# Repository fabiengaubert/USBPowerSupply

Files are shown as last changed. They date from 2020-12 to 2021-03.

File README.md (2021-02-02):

# USBPowerSupply

USB Power supply design for eurorack, works with powerbanks or good USB wallwarts

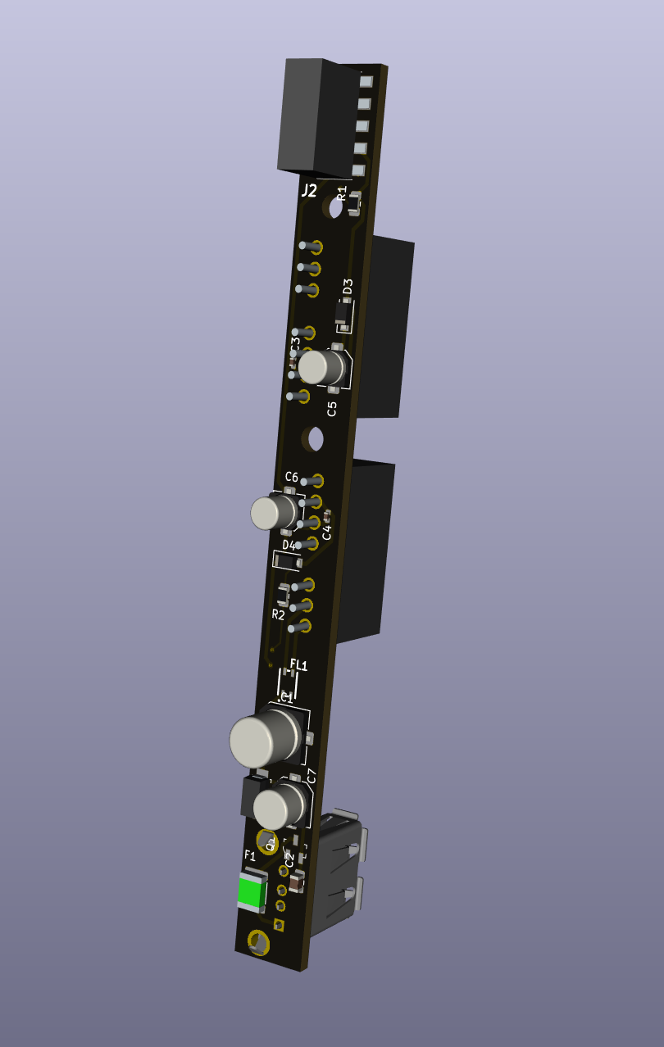
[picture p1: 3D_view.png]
3D view


- 2 HP
- 500mA at +12v, 500mA at - 12v
- efficient isolated DC-DC switching regulators with low heat release
- surge voltage and over-current protection with resettable fuse
- reversed polarity protection
- common mode choke and multiple ferrite beads with PI filters for noise filtering
- 1 LED per rail to indicated overload and short circuits

Warning and reserves:
- the two DC-DC switching regulators are expensive compared to the rest of the components: they represent about 75% of the total cost, I will work on a cheaper version with at least the same performances in the future
- the minimum voltage allowed is 4.5v, which we know can be too much for USB chargers, as they are unregulated sources of voltage. when current rises above 0.5A, most of them drop the voltage below this value. There is a need to test chargers and advise specific ones. With power banks they should be no problems as their output is regulated

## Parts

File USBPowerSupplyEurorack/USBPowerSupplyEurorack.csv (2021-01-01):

Comment | Designator | Footprint | LCSC
220uF | C1 | Capacitor_SMD:C_Elec_6.3x7.7 | C127327
22uF | C2 | Capacitor_SMD:C_0805_2012Metric | C45783
100nF | C3,C4 | Capacitor_SMD:C_0402_1005Metric | C1525
4.7uF | C5,C6 | Capacitor_SMD:C_Elec_4x5.4 | C116398
47uF | C7 | Capacitor_SMD:C_Elec_5x5.4 | C294514
SMAJ5.0CA | D1 | digikey-footprints:DO-214AC-BIPOLAR | C151931
1N4007 | D3,D4 | Diode_SMD:D_SOD-123F | C64898
1812L110 | F1 | Fuse:Fuse_1812_4532Metric | C163516
ACP3225-102-2P-T000 | FL1 | ACP3225-102-2P-T000:ACP3225 | C92126
1734366-1 | J1 | 1734366-1:TE_1734366-1
95278-501A10LF | J2 | 95278-501A10LF:95278501A10LF
RS6-0512S | PS1,PS2 | RS6-0512S:RS60512S
Q_PMOS_GSD | Q1 | digikey-footprints:SOT-23-3 | C15127
1K | R1 | Resistor_SMD:R_0805_2012Metric | C17513
Blue switch | S1 | LP4OA1PBCTR:LP4OA1PBCTR

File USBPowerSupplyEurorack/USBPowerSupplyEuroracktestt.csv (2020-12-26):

Reference | Quantity | Value | Footprint | Datasheet | Centerline_Pitch | Comment | EU_RoHS_Compliance | Number_of_Positions | Product_Type | Description | Height | Manufacturer_Name | Manufacturer_Part_Number | Mouser Part Number | Mouser Price/Stock | Arrow Part Number | Arrow Price/Stock | category | digikey description | digikey part number | lead free | library id | manufacturer | mouser part number | package | rohs | temperature range high | temperature range low | voltage
C1 | 1 | 220uF | Capacitor_SMD:C_Elec_8x10.2 | ~
C2 | 1 | 22uFMLCC | Capacitor_SMD:C_1210_3225Metric | ~
C3 C4 | 2 | 100nF MLCC | Capacitor_SMD:C_1206_3216Metric | ~
C5 C6 | 2 | 1uF | Capacitor_SMD:C_Elec_4x5.4 | ~
C7 | 1 | 47uF | Capacitor_SMD:C_Elec_6.3x5.8 | ~
D1 | 1 | SMAJ5.0CA | DIONM5026X229N | http://www.littelfuse.com/~/media/electronics/datasheets/tvs_diodes/littelfuse_tvs_diode_smaj_datasheet.pdf.pdf |  |  |  |  |  | Littelfuse SMAJ5.0CA Bi-Directional TVS Diode, 400W peak, 2-Pin DO-214AC | 2.29 | LITTELFUSE | SMAJ5.0CA | 576-SMAJ5.0CA | https://www.mouser.co.uk/ProductDetail/Littelfuse/SMAJ50CA?qs=JJML70Qc14u8hb22RFwTwA%3D%3D | SMAJ5.0CA | https://www.arrow.com/en/products/smaj5.0ca/littelfuse
D3 D4 | 2 | 1N4004 | Diode_SMD:D_SOD-123F | http://www.vishay.com/docs/88503/1n4001.pdf
F1 | 1 | 1812L110 | 1812L110_16DR:FUSC4632X125N | https://www.arrow.com/en/products/1812l11016dr/littelfuse |  |  |  |  |  | PTC Resettable Fuse 1.1A(hold) 1.95A(trip) 8VDC 100A 0.8W 0.3s 0.06Ohm SMD Solder Pad 1812 T/R | 1.25 | LITTELFUSE | 1812L110/16DR | 576-1812L110/16DR | https://www.mouser.co.uk/ProductDetail/Littelfuse/1812L110-16DR?qs=PWhpLWeW8we3Ga3SZHmLHg%3D%3D | 1812L110/16DR | https://www.arrow.com/en/products/1812l11016dr/littelfuse
J1 | 1 | 1734366-1 | 1734366-1:TE_1734366-1 |  | 2 mm[.078 in] | 1734366-1 | Compliant | 4 | Connector
J2 | 1 | 10129381-910001BLF | 10129381-910001BLF:HDRV10W67P254_2X5_1270X483X858P | https://cdn.amphenol-icc.com/media/wysiwyg/files/drawing/10129381.pdf |  |  |  |  |  | EconoStik , Board to Board connector, Unshrouded Vertical Header, Through Hole, Double Row, 10 Positions, 2.54 mm (0.100in) Pitch | 8.58 | Amphenol | 10129381-910001BLF | 649-1012938191001BLF | https://www.mouser.co.uk/ProductDetail/Amphenol-FCI/10129381-910001BLF?qs=0lQeLiL1qyYhmE%2FYsfo%2FnQ%3D%3D | 10129381-910001BLF | https://www.arrow.com/en/products/10129381-910001blf/amphenol-fci
L1 | 1 | ACM4520V-901-2P-T | eec2:TDK-ACM4520V-901-2P-T-0 | http://nl.rs-online.com/webdocs/14e9/0900766b814e92ac.pdf |  |  |  |  |  |  |  |  |  |  |  |  |  | Fuse | 2 Line Common Mode Choke Surface Mount 900 Ohm @ 100MHz 1.2A DCR 60 mOhm | 445-15677-1-ND | yes | 40a722fe90742dbf | TDK | 810-ACM4520V9012PT00 | L1808 | yes | +125°C | -40°C | 50V
PS1 PS2 | 2 | RS6-0512S | RS6-0512S:RS60512S | https://componentsearchengine.com/Datasheets/1/RS6-0512S.pdf |  |  |  |  |  | Isolated DC/DC Converters 6W 4.5-9Vin 12Vout 500mA SIP8 | 11.6 | RECOM Power | RS6-0512S | 919-RS6-0512S | https://www.mouser.co.uk/ProductDetail/RECOM-Power/RS6-0512S?qs=FLBwGrBR9%252B1rp7zTwCRMhw%3D%3D
Q1 | 1 | Q_PMOS_GSD | digikey-footprints:SOT-23-3 | https://www.mouser.fr/datasheet/2/916/PMV240SP-1919536.pdf
R1 | 1 | 510 | Resistor_SMD:R_0612_1632Metric | ~
S1 | 1 | LP4OA1PBCTR | LP4OA1PBCTR:LP4OA1PBCTR | http://spec_sheets.e-switch.com/specs/B240001.pdf |  |  |  |  |  | Pushbutton Switches DPDT On-Mom LED, Red | 19.95 | E-Switch | LP4OA1PBCTR | 612-LP4OA1PBCTR | https://www.mouser.com/Search/Refine.aspx?Keyword=612-LP4OA1PBCTR

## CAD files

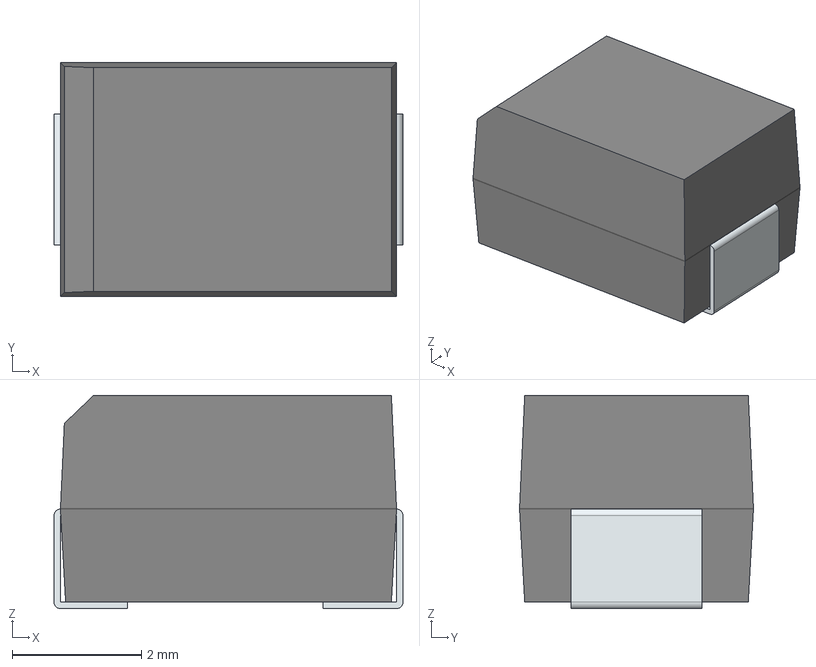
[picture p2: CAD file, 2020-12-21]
USBPowerSupplyEurorack/CustomSymbols/LIB_LSM115JE3_TR13/LSM115JE3_TR13/3D/LSM115JE3_TR13.stp
5.40 x 3.62 x 3.30 mm
FilletPin1
FilletPin2

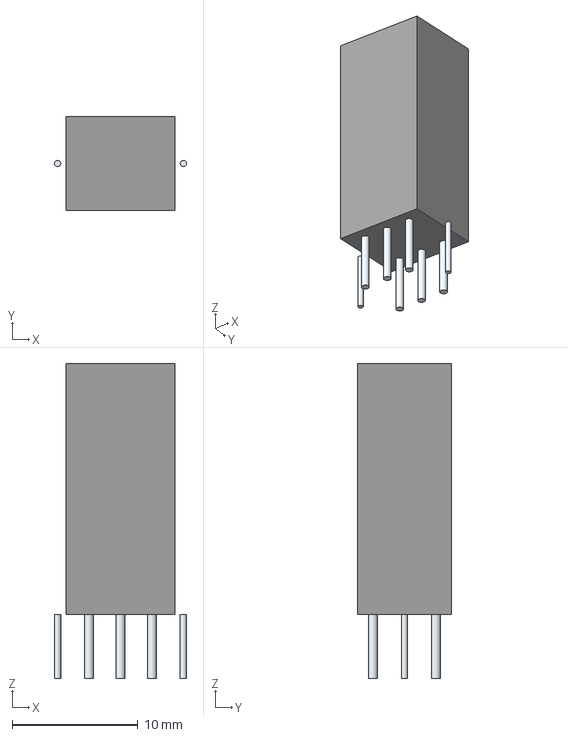
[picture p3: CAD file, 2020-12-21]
USBPowerSupplyEurorack/CustomSymbols/LP4-switch/3D/LP4OA1PBCTR.stp
10.5 x 7.50 x 25.1 mm
Leads x 8

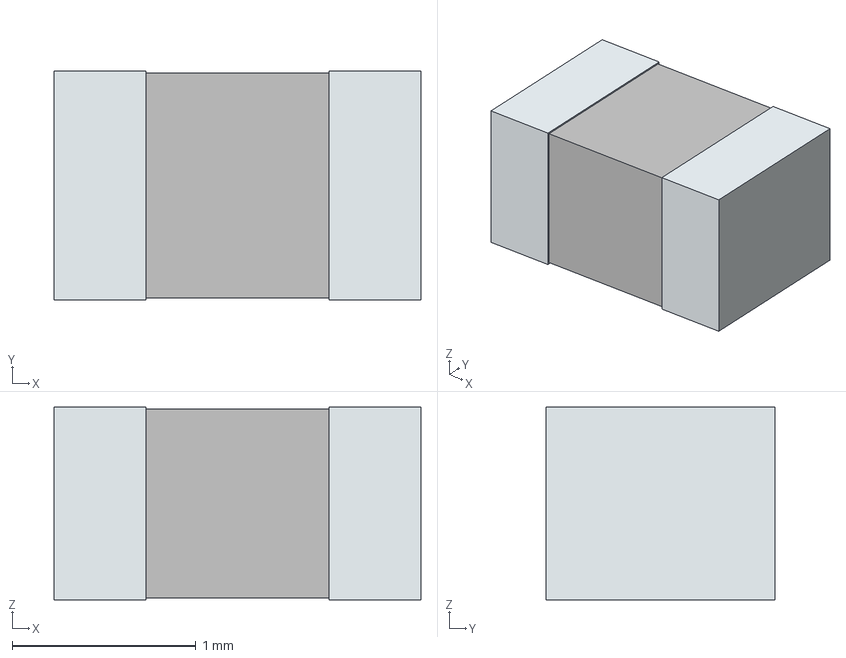
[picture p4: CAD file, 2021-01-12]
USBPowerSupplyEurorack/CustomSymbols/MPZ2012S101AT000/3D/MPZ2012S101AT000.stp
2.00 x 1.25 x 1.05 mm
term1
term2

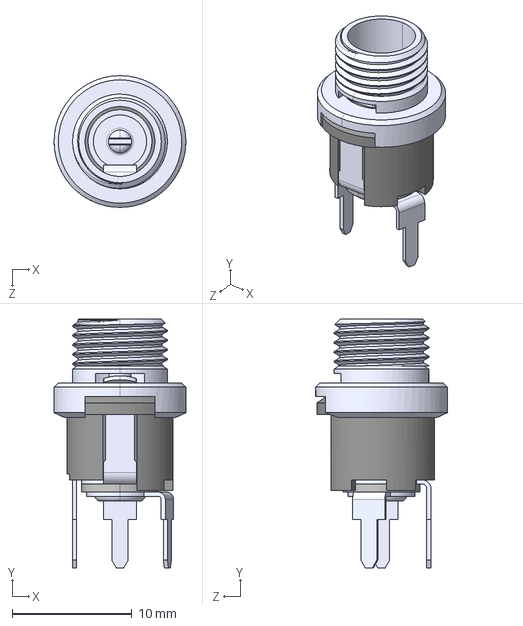
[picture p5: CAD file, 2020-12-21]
USBPowerSupplyEurorack/CustomSymbols/PC722A/PC722A.step
11.0 x 20.8 x 11.0 mm

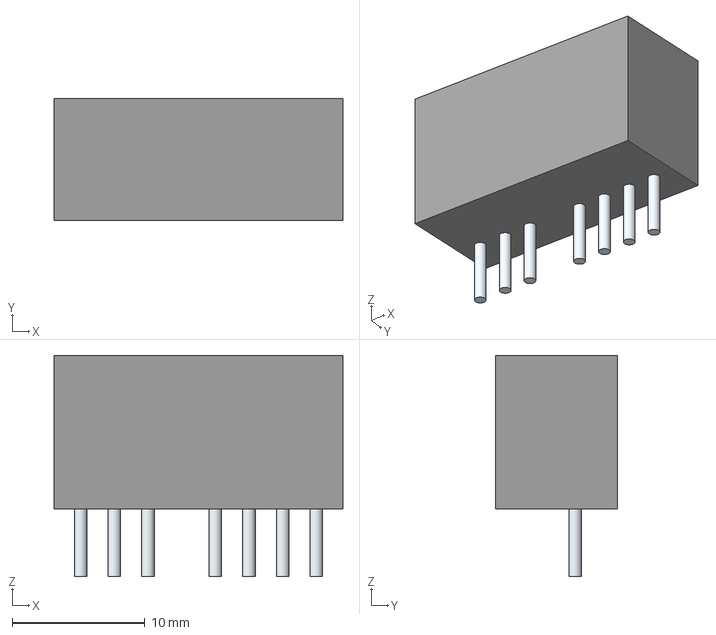
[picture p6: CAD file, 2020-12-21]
USBPowerSupplyEurorack/CustomSymbols/RS6-0512D/3D/RS6-0512D.stp
21.8 x 9.20 x 16.7 mm
Leads

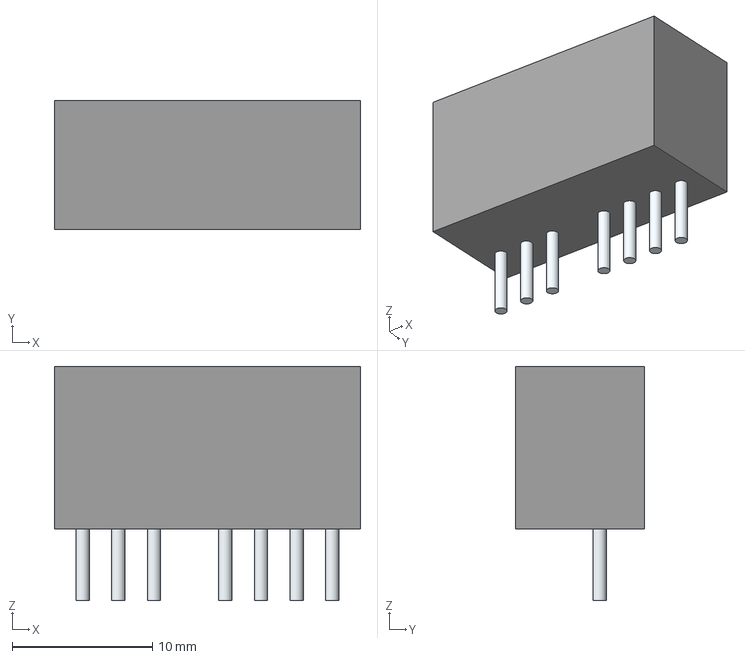
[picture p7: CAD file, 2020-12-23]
USBPowerSupplyEurorack/CustomSymbols/RS6-0512S/3D/RS6-0512S.stp
21.8 x 9.20 x 16.7 mm
Leads x 7

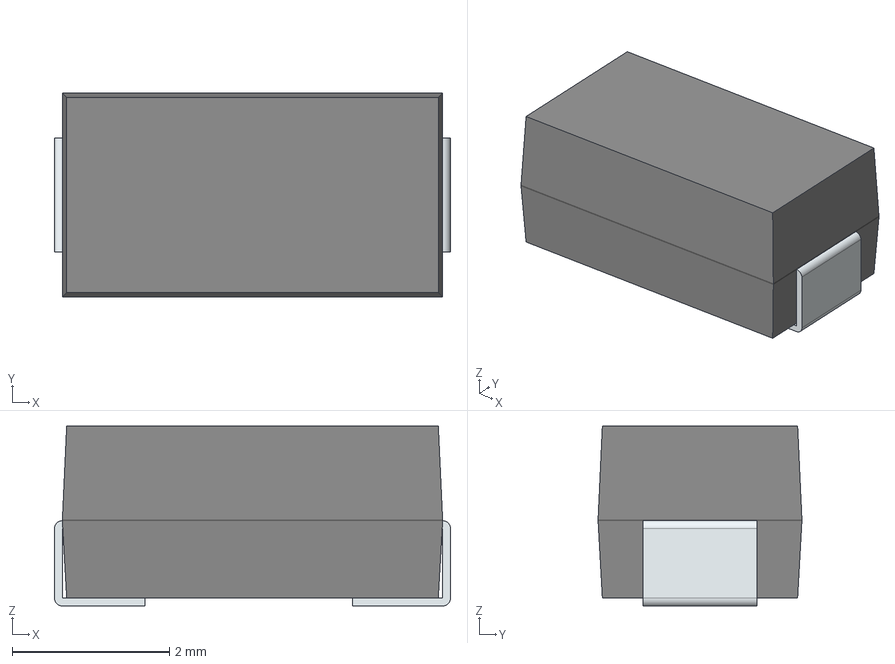
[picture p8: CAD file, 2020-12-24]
USBPowerSupplyEurorack/CustomSymbols/SMAJ5.0CA/3D/SMAJ5.0CA.stp
5.04 x 2.60 x 2.29 mm
FilletPin1
FilletPin2

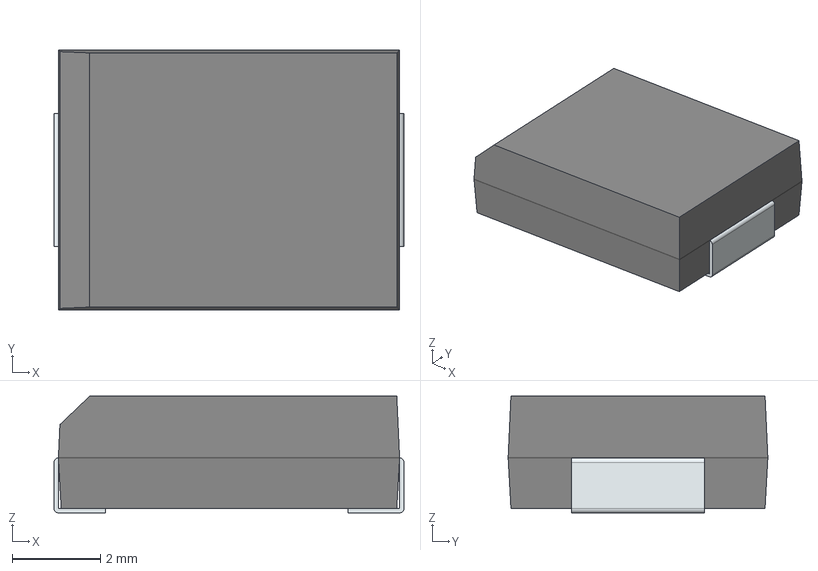
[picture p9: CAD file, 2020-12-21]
USBPowerSupplyEurorack/CustomSymbols/SS36/3D/SS36.stp
7.95 x 5.90 x 2.65 mm
FilletPin1
FilletPin2

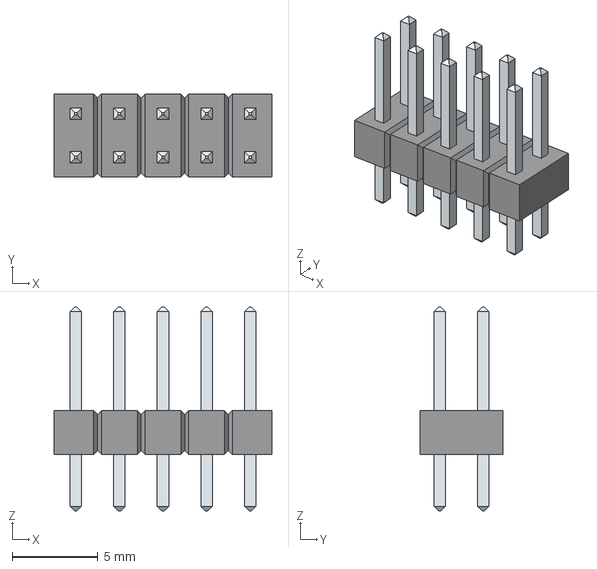
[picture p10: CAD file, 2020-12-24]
USBPowerSupplyEurorack/CustomSymbols/10129381-910001BLF/3D/10129381-910001BLF.stp
12.7 x 4.83 x 11.9 mm
LeadsArray

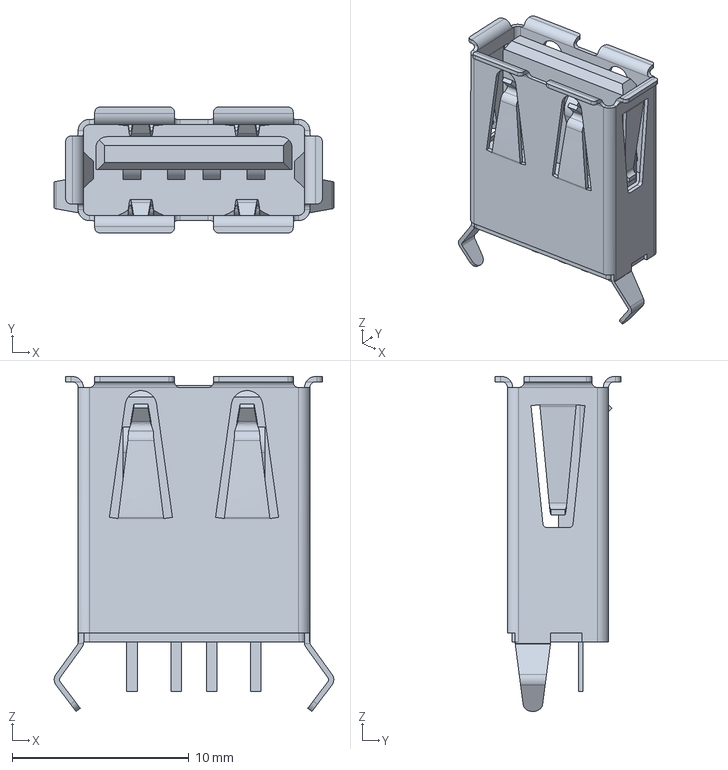
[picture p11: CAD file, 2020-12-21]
USBPowerSupplyEurorack/CustomSymbols/1734366-1/108861197-19-1734366-1/1734366-1.stp
15.8 x 7.12 x 18.9 mm

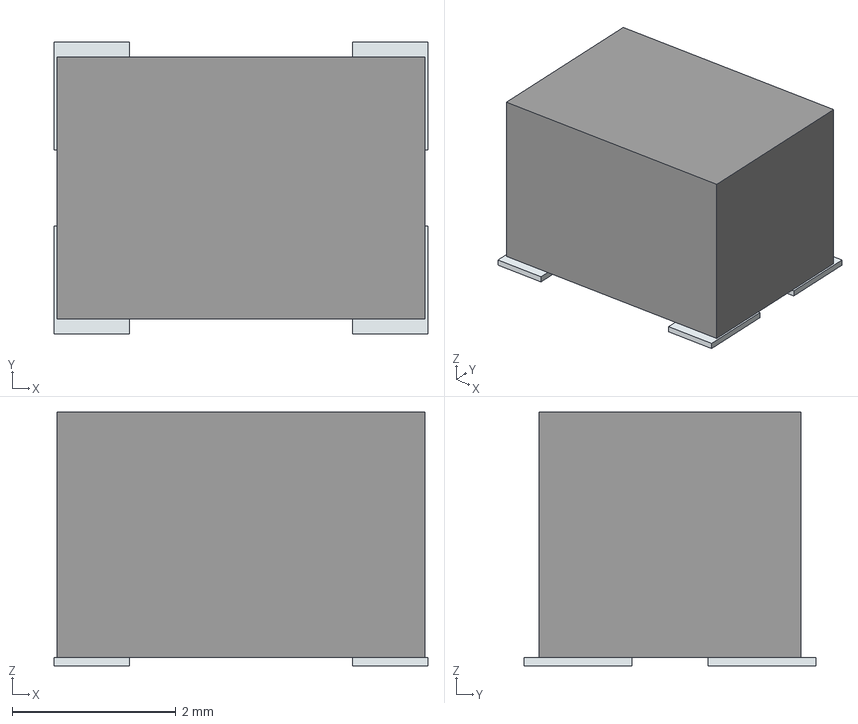
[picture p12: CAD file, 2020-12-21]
USBPowerSupplyEurorack/CustomSymbols/744235601/3D/744235601.stp
4.57 x 3.57 x 3.10 mm
Pins

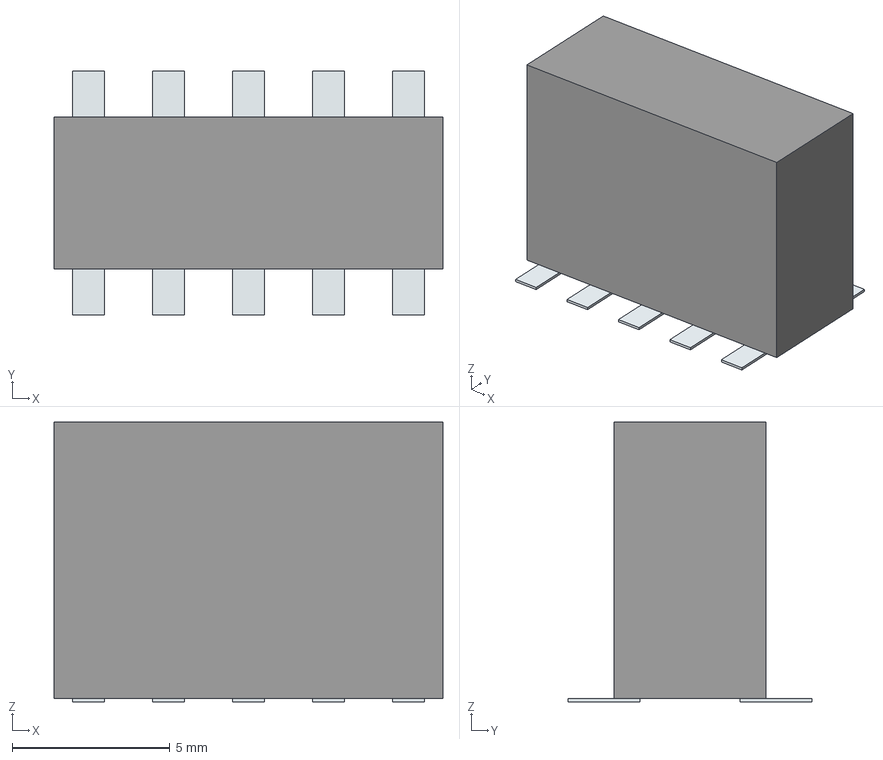
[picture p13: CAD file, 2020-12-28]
USBPowerSupplyEurorack/CustomSymbols/95278-501A10LF/3D/95278-501A10LF.stp
12.3 x 7.75 x 8.87 mm
Pins

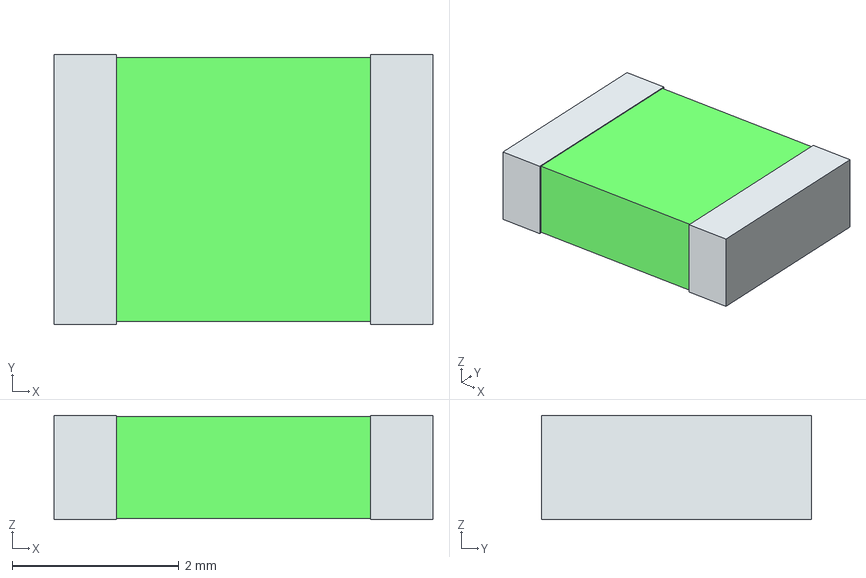
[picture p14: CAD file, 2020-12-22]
USBPowerSupplyEurorack/CustomSymbols/LIB_1812L110_16DR/3D/1812L110_16DR.stp
4.55 x 3.24 x 1.25 mm
term1
term2

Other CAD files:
USBPowerSupplyEurorack/CustomSymbols/10129381-910001BLF/3D/10129381-910001BLF.stl
USBPowerSupplyEurorack/CustomSymbols/744235601/3D/744235601.stl
USBPowerSupplyEurorack/CustomSymbols/95278-501A10LF/3D/95278-501A10LF.stl
USBPowerSupplyEurorack/CustomSymbols/LIB_1812L110_16DR/3D/1812L110_16DR.stl
USBPowerSupplyEurorack/CustomSymbols/LIB_LSM115JE3_TR13/LSM115JE3_TR13/3D/LSM115JE3_TR13.stl
USBPowerSupplyEurorack/CustomSymbols/LIB_PC722A/PC722A/Allegro/pc722a.psm
USBPowerSupplyEurorack/CustomSymbols/LIB_PC722A/PC722A/DEHDL/pc722a/chips/chips.prt
USBPowerSupplyEurorack/CustomSymbols/LP4-switch/3D/LP4OA1PBCTR.stl
USBPowerSupplyEurorack/CustomSymbols/MPZ2012S101AT000/3D/MPZ2012S101AT000.stl
USBPowerSupplyEurorack/CustomSymbols/RS6-0512D/3D/RS6-0512D.stl
USBPowerSupplyEurorack/CustomSymbols/RS6-0512S/3D/RS6-0512S.stl
USBPowerSupplyEurorack/CustomSymbols/SMAJ5.0CA/3D/SMAJ5.0CA.stl
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

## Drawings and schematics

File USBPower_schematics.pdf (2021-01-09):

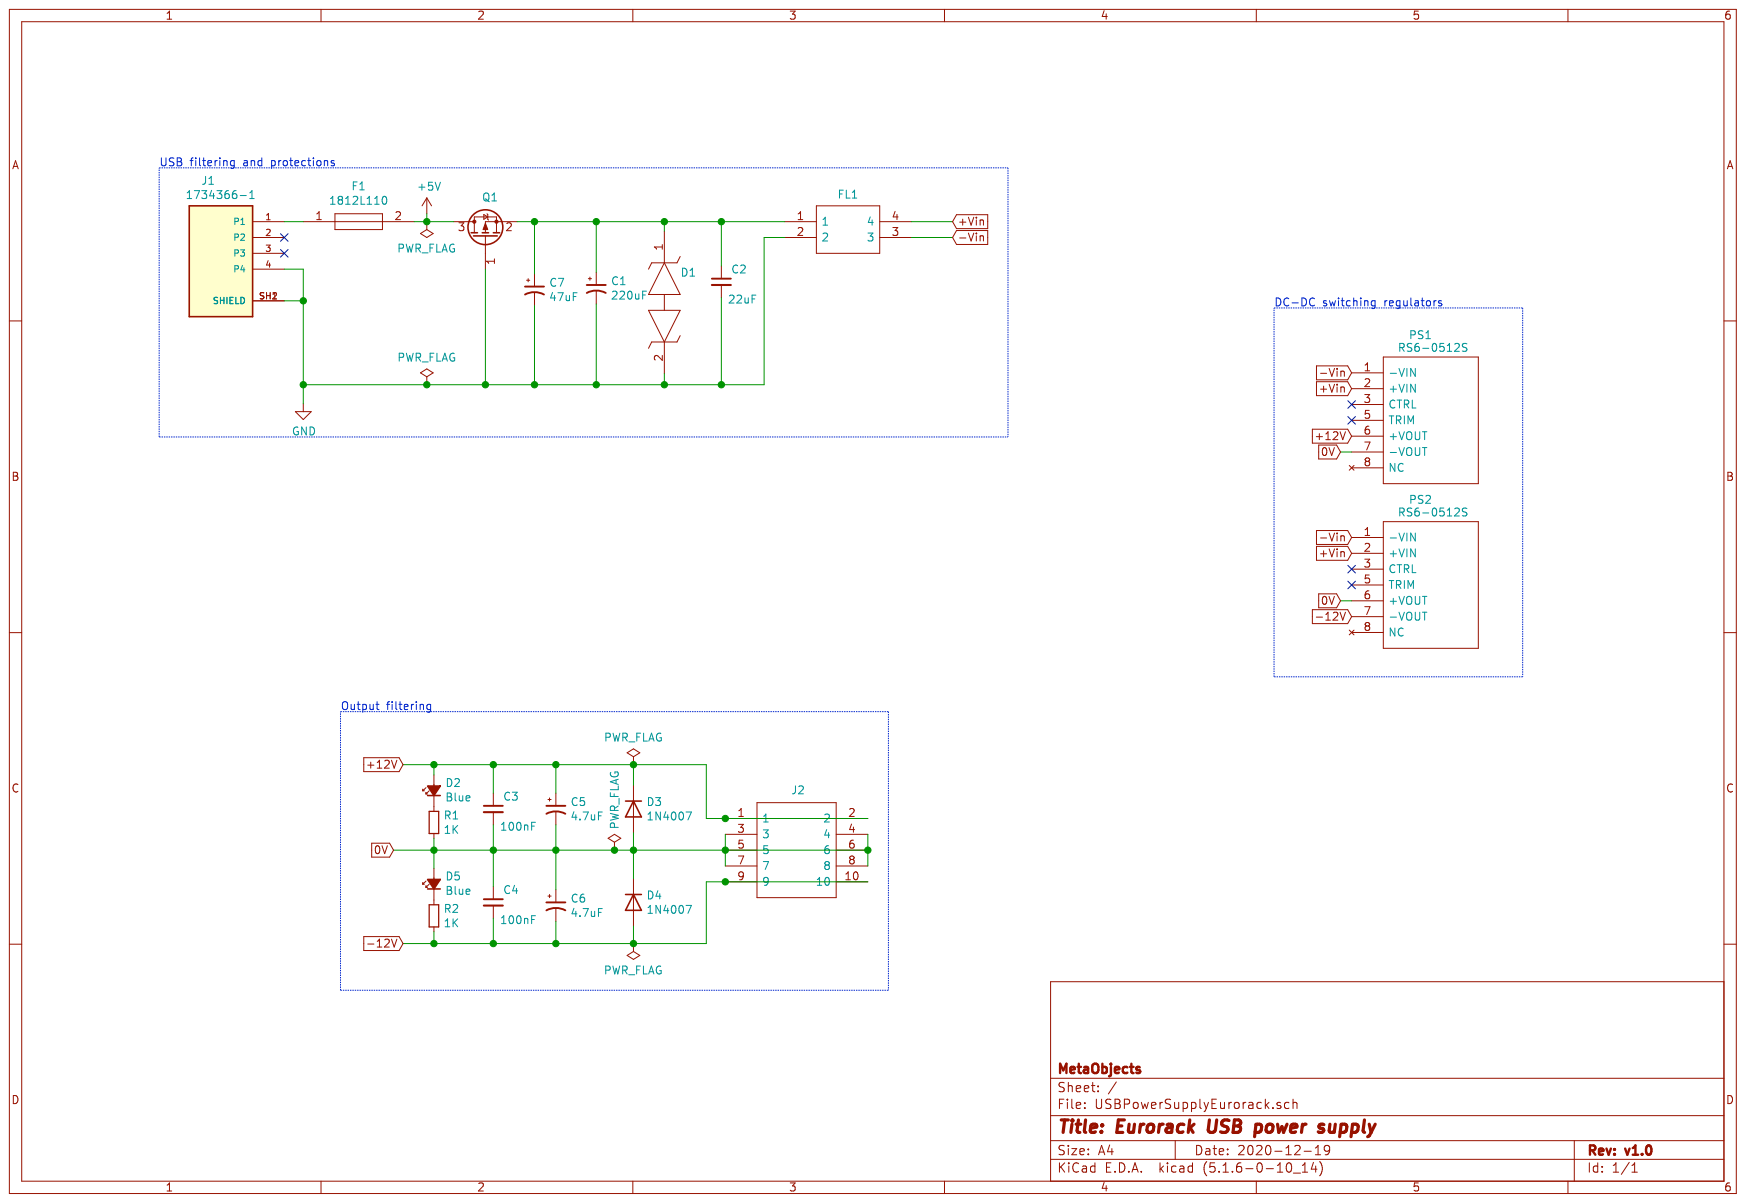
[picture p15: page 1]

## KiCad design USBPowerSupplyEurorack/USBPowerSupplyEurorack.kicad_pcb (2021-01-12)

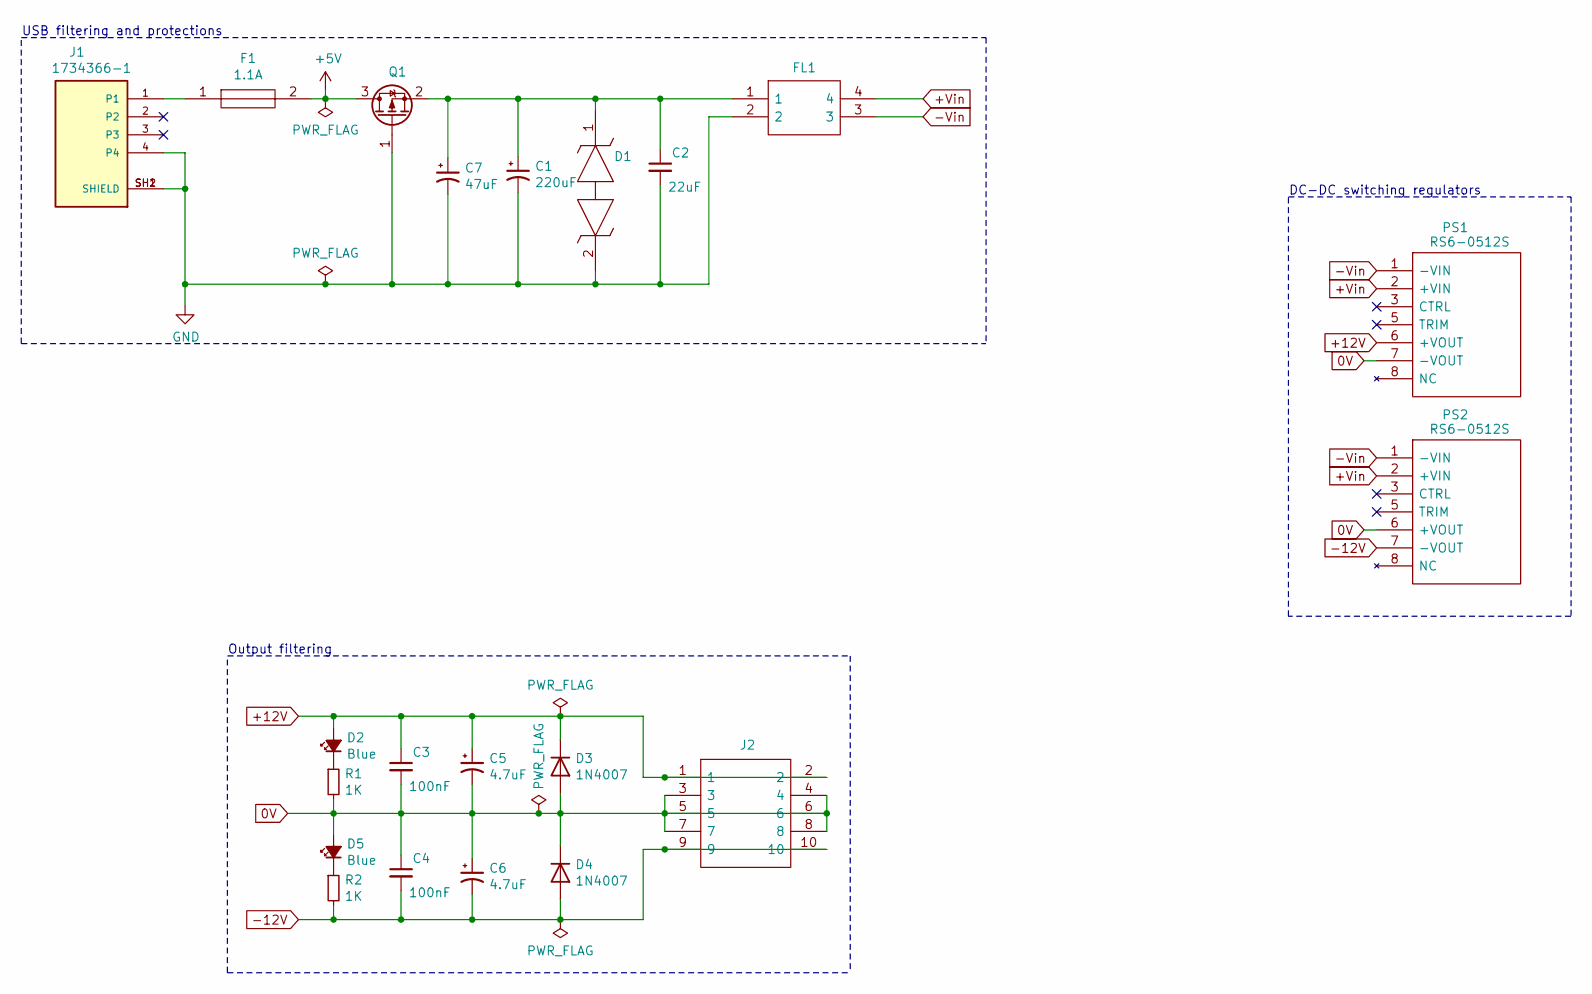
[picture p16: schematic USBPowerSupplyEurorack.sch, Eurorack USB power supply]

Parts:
C1: 220uF; C_Elec_6.3x7.7; LCSC C127327
C2: 22uF; C_0805_2012Metric; LCSC C45783
C3, C4: 100nF; C_0402_1005Metric; LCSC C1525
C5, C6: 4.7uF; C_Elec_4x5.4; LCSC C116398
C7: 47uF; C_Elec_5x5.4; LCSC C294514
D1: SMAJ5.0CA; DO-214AC-BIPOLAR; Manufacturer_Part_Number SMAJ5.0CA; Mouser Part Number 576-SMAJ5.0CA
D2, D5: Blue; LED_0603
D3, D4: 1N4007; D_SOD-123F; LCSC C64898
F1: 1.1A; Fuse_1812_4532Metric; Manufacturer_Part_Number 1812L110/16DR; Mouser Part Number 576-1812L110/16DR
FL1: ACP3225-102-2P-T000; ACP3225; Manufacturer_Part_Number ACP3225-102-2P-T000; Mouser Part Number 810-ACP32251022PT000
J1: 1734366-1; TE_1734366-1
J2: 95278-501A10LF; 95278501A10LF; Manufacturer_Part_Number 95278-501A10LF; Mouser Part Number 649-95278-501A10LF
PS1, PS2: RS6-0512S; RS60512S; Manufacturer_Part_Number RS6-0512S; Mouser Part Number 919-RS6-0512S
Q1: Q_PMOS_GSD; SOT-23-3; LCSC C15127
R1, R2: 1K; R_0805_2012Metric; LCSC C17513

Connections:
0V: C3.2, C4.1, C5.2, C6.1, D3.2 (A), D4.1 (K), D5.2 (A), J2.3, J2.4, J2.5, J2.6, J2.7, J2.8, PS1.7 (-VOUT), PS2.6 (+VOUT), R1.2
+5V: F1.2, Q1.3 (D)
+12V: C3.1, C5.1, D2.2 (A), D3.1 (K), J2.1, J2.2, PS1.6 (+VOUT)
+Vin: FL1.4, PS1.2 (+VIN), PS2.2 (+VIN)
-12V: C4.2, C6.2, D4.2 (A), J2.9, J2.10, PS2.7 (-VOUT), R2.2
-Vin: FL1.3, PS1.1 (-VIN), PS2.1 (-VIN)
GND: C1.2, C2.2, C7.2, D1.2, FL1.2, J1.4, J1.SH1 (SHIELD), J1.SH2 (SHIELD), Q1.1 (G)
unnamed: C1.1, C2.1, C7.1, D1.1, FL1.1, Q1.2 (S)
unnamed: D2.1 (K), R1.1
unnamed: D5.1 (K), R2.1
unnamed: F1.1, J1.1

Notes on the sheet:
USB filtering and protections
DC-DC switching regulators
Output filtering

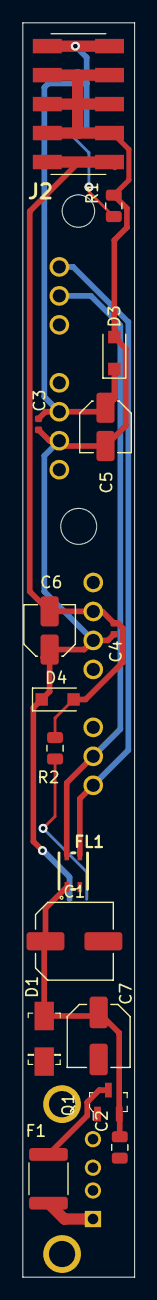
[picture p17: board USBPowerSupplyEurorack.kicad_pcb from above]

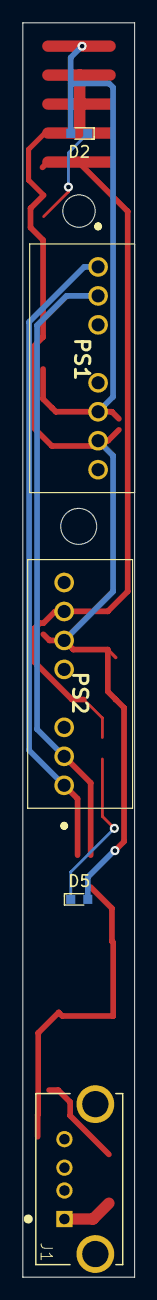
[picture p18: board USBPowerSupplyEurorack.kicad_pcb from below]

Board: 2 copper layers, 9.8 x 110.0 mm, 21 parts (5 on the bottom side), 11 nets.

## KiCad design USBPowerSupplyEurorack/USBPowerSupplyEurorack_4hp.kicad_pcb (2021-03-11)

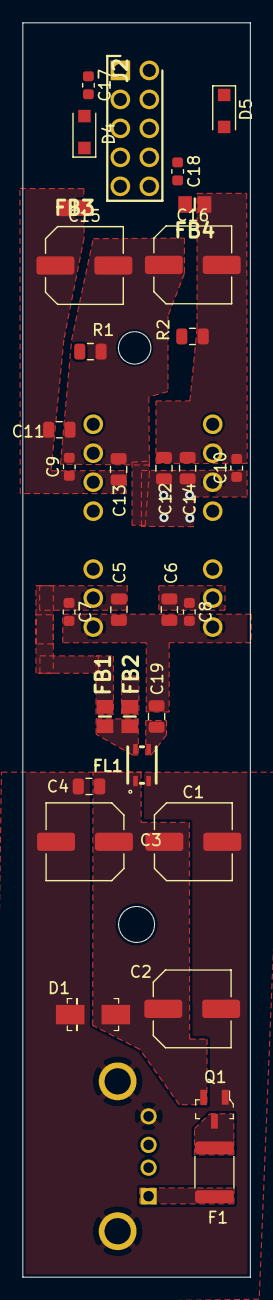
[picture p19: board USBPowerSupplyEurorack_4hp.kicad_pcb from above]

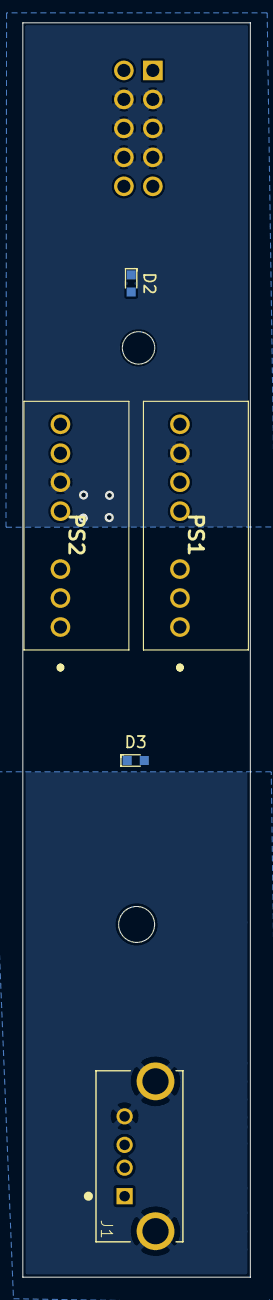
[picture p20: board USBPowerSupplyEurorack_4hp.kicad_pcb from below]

Board: 2 copper layers, 19.9 x 110.0 mm, 37 parts (5 on the bottom side), 16 nets, no tracks yet.

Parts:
C1, C15, C16: 47uF; C_Elec_6.3x5.4
C2, C3: 220uF; C_Elec_6.3x7.7
C4, C5, C6, C11, C12, C13, C14: 22uF; C_0805_2012Metric
C7, C8, C9, C10, C17, C18: 100nF; C_0603_1608Metric
C19: 10uF; C_0805_2012Metric
D1: SMAJ5.0CA; DO-214AC-BIPOLAR
D2, D3: Blue; LED_0603
D4, D5: 1N4007; D_SOD-123F
F1: 3A hold; Fuse_1812_4532Metric
FB1, FB2, FB3, FB4: C15957; BEADC2012X105N
FL1: ACP3225-102-2P-T000; ACP3225
J1: 1734366-1; TE_1734366-1
J2: 10129381-910001BLF; HDRV10W67P254_2X5_1270X483X858P
PS1, PS2: RS6-0512S; RS60512S
Q1: Q_PMOS_GSD; SOT-23-3
R1, R2: 1K; R_0805_2012Metric

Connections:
0V: C9.2, C10.1, C11.2, C12.1, C13.2, C14.1, C15.2, C16.1, C17.2, C18.1, D3.2, D4.2, D5.1, J2.3, J2.4, J2.5, J2.6, J2.7, J2.8, PS1.7, PS2.6, R1.2
+5V: F1.2, Q1.3
+12V: C9.1, C11.1, C13.1, C15.1, D2.2, FB3.2, PS1.6
+Vin1: C5.1, C7.1, FB1.1, PS1.2
+Vin2: C6.1, C8.1, FB2.1, PS2.2
-12V: C10.2, C12.2, C14.2, C16.2, FB4.2, PS2.7, R2.2
-Vin1: C5.2, C6.2, C7.2, C8.2, C19.2, PS1.1, PS2.1
GND: C1.2, C2.2, C3.2, C4.2, D1.2, FL1.2, J1.4, J1.SH1, J1.SH2, Q1.1
unnamed: C1.1, C2.1, C3.1, C4.1, D1.1, FL1.1, Q1.2
unnamed: C17.1, D4.1, FB3.1, J2.1, J2.2
unnamed: C18.2, D5.2, FB4.1, J2.9, J2.10
unnamed: C19.1, FL1.3
unnamed: D2.1, R1.1
unnamed: D3.1, R2.1
unnamed: F1.1, J1.1
unnamed: FB1.2, FB2.2, FL1.4

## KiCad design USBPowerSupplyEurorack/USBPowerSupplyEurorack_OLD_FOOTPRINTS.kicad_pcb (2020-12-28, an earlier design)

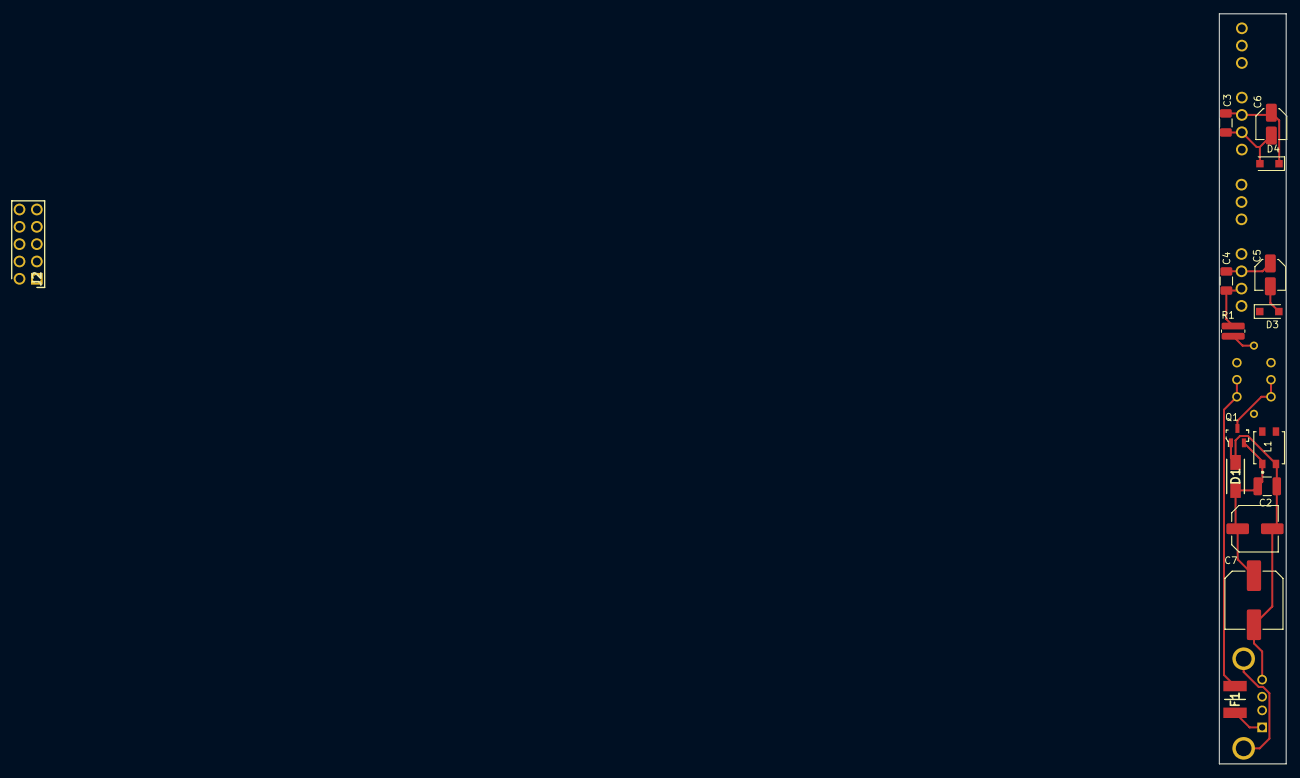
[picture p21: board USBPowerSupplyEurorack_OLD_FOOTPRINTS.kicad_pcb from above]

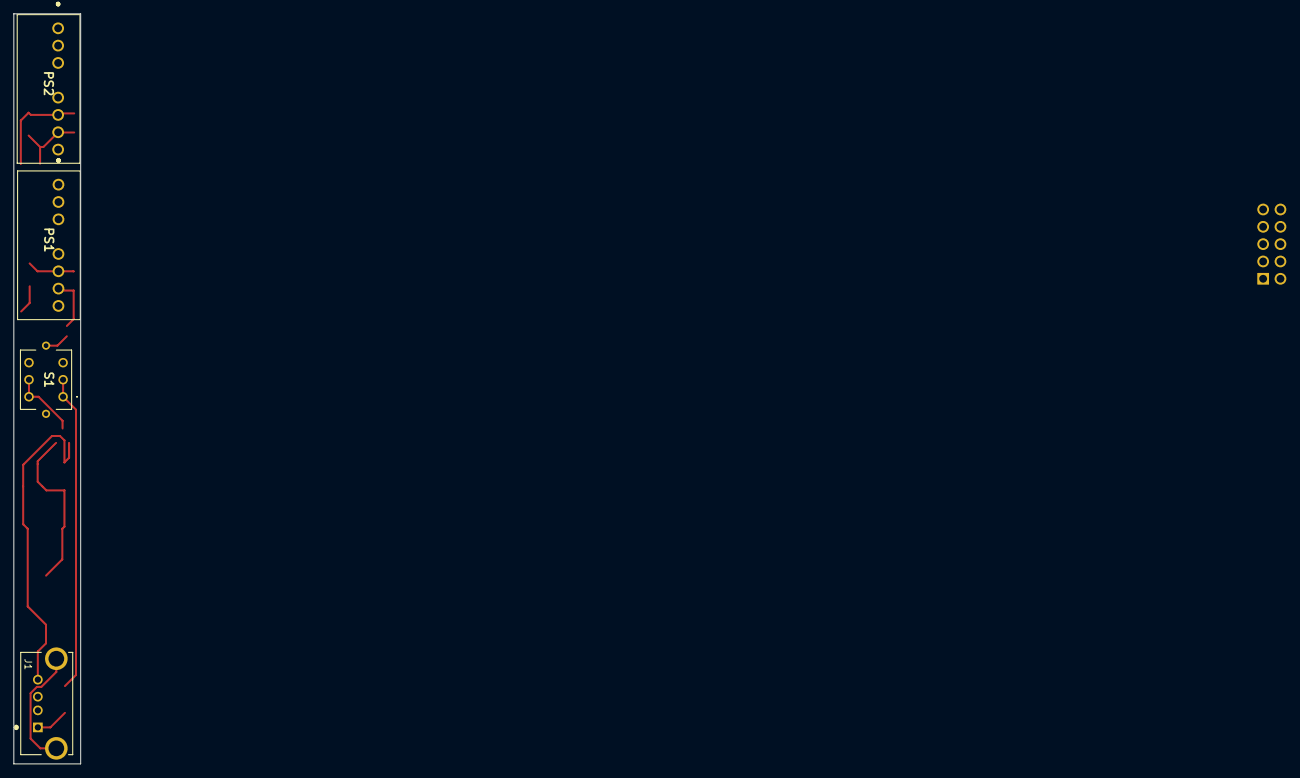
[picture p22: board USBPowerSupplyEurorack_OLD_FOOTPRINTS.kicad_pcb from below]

Board: 2 copper layers, 9.8 x 110.0 mm, 19 parts (4 on the bottom side), 12 nets.

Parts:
C1: 220uF; C_Elec_8x10.2
C2: 22uFMLCC; C_1210_3225Metric
C3, C4: 100nF MLCC; C_1206_3216Metric
C5, C6: 1uF; C_Elec_4x5.4
C7: 47uF; C_Elec_6.3x5.8
D1: SMAJ5.0CA; DIONM5026X229N
D3, D4: 1N4004; D_SOD-123F
F1: 1812L110; FUSC4632X125N
J1: 1734366-1; TE_1734366-1
J2: 10129381-910001BLF; HDRV10W67P254_2X5_1270X483X858P
L1: ACM4520V-901-2P-T; TDK-ACM4520V-901-2P-T-0
PS1, PS2: RS6-0512S; RS60512S
Q1: Q_PMOS_GSD; SOT-23-3
R1: 510; R_0612_1632Metric
S1: LP4OA1PBCTR

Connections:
0V: C3.1, C4.2, C5.2, C6.1, D3.2, D4.1, J2.3, J2.4, J2.5, J2.6, J2.7, J2.8, PS1.7, PS2.6, R1.2
+5V: Q1.3, S1.4, S1.5
+5VD: F1.2, S1.1, S1.2
+12V: C4.1, C5.1, D3.1, J2.1, J2.2, PS1.6, S1.L1
+Vin: L1.4, PS1.2, PS2.2
-12V: C3.2, C6.2, D4.2, J2.9, J2.10, PS2.7
-Vin: L1.3, PS1.1, PS2.1
GND: C1.2, C2.2, C7.2, D1.2, J1.4, L1.2, Q1.1
unnamed: C1.1, C2.1, C7.1, D1.1, L1.1, Q1.2
unnamed: F1.1, J1.1
unnamed: J1.SH1, J1.SH2
unnamed: R1.1, S1.L2

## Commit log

2020-12-21 created KiCAD project with basic components
    [EDI2CAP.CFG, PC722A.step, USBPowerSupplyEurorack.kicad_pcb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]
2020-12-21 added component footprints and going forward on schematics
    [1734366-1.stp, LP4OA1PBCTR.stl, LP4OA1PBCTR.stp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]
2020-12-21 added common choke and other components
    [744235601.stl, 744235601.stp]
2020-12-21 changed diode for lower forward voltage, prepared 2HP PCB contour
    [LSM115JE3_TR13.stl, LSM115JE3_TR13.stp, USBPowerSupplyEurorack.kicad_pcb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]
2020-12-22 completed schematics
    [USBPowerSupplyEurorack.kicad_pcb, USBPowerSupplyEurorack.sch]
2020-12-22 finished schematics, added PMOS for reversed polarity protection
    [1812L110_16DR.stl, 1812L110_16DR.stp, USBPowerSupplyEurorack.sch]
2020-12-23 replaced dual regulator by two regulators for more current
    [RS6-0512S.stl, RS6-0512S.stp]
2020-12-23 finished schematics
    [USBPowerSupplyEurorack.sch]
2020-12-24 replaced power plug with open one
    [10129381-910001BLF.stl, 10129381-910001BLF.stp, USBPowerSupplyEurorack.sch]
2020-12-24 added footprints with LCSC components
    [TDK_-_ACM4520V-901-2P-T.step, USBPowerSupplyEurorack.sch]
2020-12-24 changed TVS symbol as footprint was not valid
    [SMAJ5.0CA.stl, SMAJ5.0CA.stp, USBPowerSupplyEurorack.kicad_pcb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]
2020-12-24 updated all footprints in pcbnew
    [USBPowerSupplyEurorack.kicad_pcb]
2020-12-25 placed components on the PCB
    [USBPowerSupplyEurorack.kicad_pcb, USBPowerSupplyEurorack.sch]
2020-12-25 routing test for price evaluation
    [USBPowerSupplyEurorack-B_Cu.gbr, USBPowerSupplyEurorack-B_Mask.gbr, USBPowerSupplyEurorack-B_Paste.gbr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]
2020-12-26 connected switch to control the DC-DC converters
    [USBPowerSupplyEurorack-B_Cu.gbr, USBPowerSupplyEurorack-B_Mask.gbr, USBPowerSupplyEurorack-B_Paste.gbr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]
2020-12-28 changing footprints for JLC available parts
    [USBPowerSupplyEurorack.sch]
2020-12-28 finished updating footprints, edited TVS diode's footprint
    [USBPowerSupplyEurorack.kicad_pcb, USBPowerSupplyEurorack.sch, USBPowerSupplyEurorack_OLD_FOOTPRINTS.kicad_pcb]
2020-12-28 placed components, need to change power 2x5 for SMT
    [USBPowerSupplyEurorack.kicad_pcb]
2020-12-28 replaced power header for SMT, finished placement
    [95278-501A10LF.stl, 95278-501A10LF.stp, USBPowerSupplyEurorack.kicad_pcb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]
2020-12-28 worked a components placement
    [USBPowerSupplyEurorack.kicad_pcb]
2020-12-29 simplified schematics
    [USBPowerSupplyEurorack.sch]
2020-12-30 added 3D models
    [USBPowerSupplyEurorack.kicad_pcb, USBPowerSupplyEurorack.sch]
2020-12-30 naive routing to try
    [USBPowerSupplyEurorack.kicad_pcb]
2021-01-01 removed switch and simplified schematics, added a second LED for -12v
    [USBPowerSupplyEurorack-B_Cu.gbr, USBPowerSupplyEurorack-B_Mask.gbr, USBPowerSupplyEurorack-B_Paste.gbr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]
2021-01-03 changed footprints placement, added the two LEDs
    [USBPowerSupplyEurorack.kicad_pcb, USBPowerSupplyEurorack.sch]
2021-01-08 added LEDs, all components are placed now
    [USBPowerSupplyEurorack.kicad_pcb, USBPowerSupplyEurorack.sch]
2021-01-08 new naive routing
    [USBPowerSupplyEurorack.kicad_pcb, USBPowerSupplyEurorack.sch]
2021-01-09 final placement
    [USBPowerSupplyEurorack.kicad_pcb]
2021-01-12 going to 4hp for better routing
    [USBPowerSupplyEurorack.kicad_pcb, USBPowerSupplyEurorack.sch, USBPowerSupplyEurorack_4hp.kicad_pcb]
2021-01-12 naive placement and routing
    [USBPowerSupplyEurorack_4hp.kicad_pcb]
2021-01-12 changed caps on schematics, added PI filter and bigger caps as we have now 4HP
    [USBPowerSupplyEurorack.sch, USBPowerSupplyEurorack_4hp.kicad_pcb]
2021-01-12 updated footprints
    [MPZ2012S101AT000.stl, MPZ2012S101AT000.stp, USBPowerSupplyEurorack.sch]
2021-01-12 new components placement
    [USBPowerSupplyEurorack.sch, USBPowerSupplyEurorack_4hp.kicad_pcb]
2021-01-12 still testing routing
    [USBPowerSupplyEurorack_4hp.kicad_pcb]
2021-01-13 changing placement of components
    [USBPowerSupplyEurorack_4hp.kicad_pcb]
2021-01-18 resizing components for max 3A input current
2021-01-18 changed some components for matching current ratings
    [USBPowerSupplyEurorack.sch]
2021-01-20 finished updating condensators to the right voltage rating, updated BOM and footprints
    [USBPowerSupplyEurorack.sch, USBPowerSupplyEurorack_4hp.kicad_pcb]
2021-01-21 updated information in readme after schematics modifications multiple schematics modifications
    [USBPowerSupplyEurorack_4hp.kicad_pcb]
2021-01-21 updated components and footprints
    [USBPowerSupplyEurorack.sch, USBPowerSupplyEurorack_4hp.kicad_pcb]
2021-01-26 moved holes for panel, updated power plug
    [USBPowerSupplyEurorack.sch, USBPowerSupplyEurorack_4hp.kicad_pcb]
2021-01-27 working on the routing, making copper pours
    [USBPowerSupplyEurorack_4hp.kicad_pcb]
2021-03-11 changed mistake in schematics
    [USBPowerSupplyEurorack.sch, USBPowerSupplyEurorack_4hp.kicad_pcb]
